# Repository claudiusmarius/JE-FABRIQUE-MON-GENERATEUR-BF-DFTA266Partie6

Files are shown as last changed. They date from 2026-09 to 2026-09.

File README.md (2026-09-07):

# JE-FABRIQUE-MON-GENERATEUR-BF-DFTA266Partie6

Générateur BF DDS -- AD9833 / Seeeduino XIAO / ATtiny85

Vidéo YouTube : https://youtu.be/ANECuOo78Ss

Présentation

Ce projet est la réalisation d'un générateur de fonctions basse
fréquence (BF) basé sur le circuit DDS AD9833, piloté par un
Seeeduino XIAO SAMD21 et associé à un ATtiny85.

L'appareil fournit trois formes d'onde :

Sinus

Triangle

Rectangle

La fréquence est sélectionnée par plages puis ajustée par appui sur deux boutons
poussoirs. Un afficheur OLED indique la fréquence et la forme d'onde
sélectionnée.

Le générateur dispose également de réglages de niveau, d'amplitude/gain
et d'offset, ainsi que d'un étage de sortie à transistors
complémentaires.

Architecture

Génération DDS

Le signal est produit par l'AD9833, commandé par le Seeeduino XIAO.

Le XIAO assure notamment : 
- la programmation de la fréquence ;
- la sélection de la forme d'onde ;
- la gestion des boutons ;
- la gestion de l'afficheur OLED.

Gestion des modes

Un ATtiny85 intervient dans la gestion des modes, notamment pour
l'atténuation automatique appliquée en mode rectangle afin de rapprocher
son niveau de celui des signaux sinus et triangle.

Traitement du signal

Le signal DDS est traité sur une carte analogique comprenant notamment
des NE5532 et un LT1006.

Cette partie assure : 
- l'adaptation du niveau ;
- le réglage del'amplitude ;
- le réglage de l'offset ;
- le traitement nécessaire avant l'étage de sortie.

Étage de sortie

L'étage de sortie utilise une paire complémentaire BD139 / BD140 en
push-pull.

La contre-réaction est prélevée à la jonction des deux résistances
d'émetteur, avant la résistance série de sortie. Elle participe à la
correction du fonctionnement de l'étage et à la réduction de la
distorsion de croisement.

Alimentation

L'appareil est alimenté en 24 V DC.

Une carte dédiée permet de créer une alimentation symétrique : - +12 V -
0 V - −12 V

Une même conception de PCB est utilisée, avec une implantation
différente, pour l'alimentation symétrique et pour l'étage push-pull.

Face avant

La face avant regroupe :

bouton d'augmentation de fréquence ;

bouton de diminution de fréquence ;

sélection de plage ;

sélection de forme d'onde ;

réglage du niveau du signal DDS ;

réglage du gain/amplitude ;

réglage d'offset ;

LED d'indication des modes ;

afficheur OLED ;

bornes de sortie.

Alimentation logique en 3,3 V

Au cours du développement, l'AD9833, l'ATtiny85 et l'afficheur OLED ont
été utilisés en 3,3 V, afin d'homogénéiser le domaine logique avec
le XIAO.

Cette évolution a également fait partie des essais visant à améliorer la
fiabilité du système lors des mises sous tension répétées.

Essais et mise au point

Le projet a été développé progressivement à partir d'essais sur
breadboard, de simulations, de mesures à l'oscilloscope et de
réalisations de PCB.

Des essais de fonctionnement prolongé et des cycles répétés de mise sous
tension ont également été réalisés.

Plusieurs corrections ont été apportées au cours du développement.

ERRATUMS

Les erreurs identifiées dans les schémas ou les PCB sont regroupées dans
la documentation sous la forme :

ERRATUM N°1, ERRATUM N°2, etc.

Chaque erratum précise : - l'erreur constatée ; - sa conséquence
éventuelle ; - la correction à appliquer ; - la révision de PCB
concernée.

Consulter impérativement les erratums avant toute reproduction d'une
carte.

Vidéos

Le projet est documenté sur YouTube sous la référence DFTA266 --
Générateur BF DDS.

Les liens vers les différentes vidéos peuvent être ajoutés dans cette
section.

Contenu du dépôt

Le dépôt peut notamment contenir :

schémas électroniques ;

fichiers PCB ;

fichiers Gerber ;

programmes du Seeeduino XIAO ;

programme de l'ATtiny85 ;

documentation technique ;

photographies ;

documents complémentaires ;

erratums et corrections.

Avertissement

Ce projet est une réalisation personnelle de laboratoire.

Les fichiers sont publiés pour documenter la conception et permettre à
d'autres passionnés d'étudier ou de reproduire le projet.

Avant toute reproduction, vérifier les schémas, les valeurs des
composants et les erratums correspondant à la révision du PCB
utilisée.

Contactez moi en cas de doute

Auteur

Claude DUFOURMONT

Projet personnel -- Générateur BF DDS

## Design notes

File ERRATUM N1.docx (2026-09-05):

ERRATUM N°1

Erreur constatée :

Sur certaines remises sous tension les ports du Seeeduino XIAO de niveau 3.3V étaient parfois perturbés vis les ports de 3 autres matériels alimentés en +5V.

PCB concerné :

DFTA266TER

Conséquences :

Ces perturbations pouvaient détruire dans certains cas le Seeeduino XIAO

Matériels impliqués :

AD9833

ATtiny85

Ecran OLED

Correction :

Le +5V continue d’alimenter le Seeeduino XIAO via la diode D3.

Le +3.3V du Seeeduino XIAO est utilisé pour se substituer aux pistes +5V des 3 matériels cités précédemment.

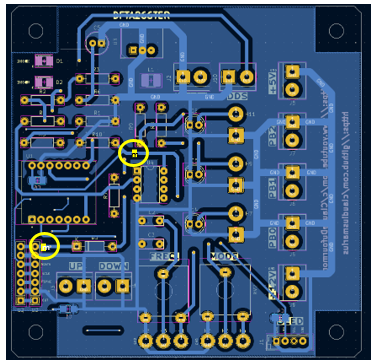
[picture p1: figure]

COUPURES DE PISTES SUR LA FACE B

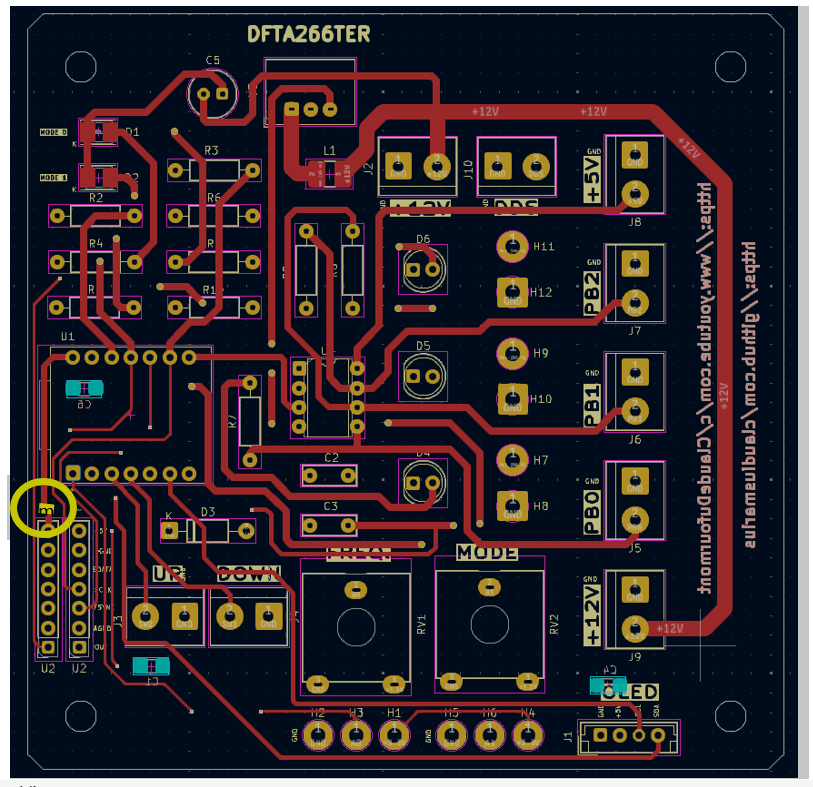
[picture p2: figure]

COUPURES DE PISTES SUR LA FACE F

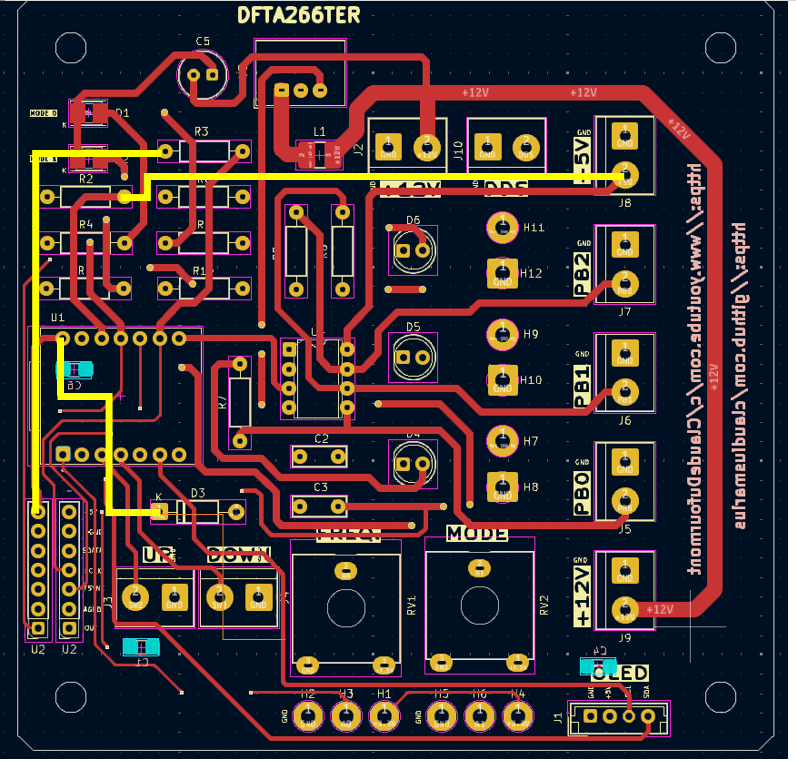
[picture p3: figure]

MISE EN PLACE DE NOUVELLES LIAISONS (sur la face de son choix)

Avant de procéder à la remis sous tension déposer le Seeeduino XIAO, l’AD9833, l’ATtiny85, l’écran OLED.

Mettre sous tension et

vérifier la présence de 5V sur le socket broche 14 du Seeeduino XIAO.

Vérifier l’absence de tension d’alimentation sur les connecteurs AD9833 ATtiny85 et OLED

Couper l’alimentation et mettre en place le Seeeduino XIAO, remettre sous tension.

Vérifier sur les connecteurs de AD9833, ATtiny85 et OLED la présence de 3.3V

Placer les 3 derniers composants et vérifier le bon fonctionnement.

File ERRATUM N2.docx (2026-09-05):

ERRATUM N°2

Erreur constatée :

Lorsque le PCB est utilisé pour la fonction DUAL SUPPLY, l’entrée moins de U1 aurait du être raccordée directement au GND c’est-à-dire au point d’intersection de R3 et R4

PCB concerné :

DFTA266Partie6

Conséquences :

Fonction inopérante

Matériels impliqués :

U1 ( AOP LT1006)

Correction :

Couper la liaison entre l’entrée moins de U1 (2) et sa sortie (6)

Couper la liaison entre l’entrée moins de U1 (2) et la résistance R11

Relier la sortie (6) à la résistance R11

Relier l’entrée moins de U1 à l’intersection de R3 et R4 qui est la masse virtuelle

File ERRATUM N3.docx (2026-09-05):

ERRATUM N°3

Erreur constatée :

Lorsque le PCB est utilisé pour la fonction DUAL SUPPLY, mais aussi pour la fonction PUSH PULL, une erreur d’inattention m’a fait inverser bas et collecteur de Q1, cette erreur est donc répercutée sur le PCB.

Pour la fonction PUSH PULL uniquement et pour des raisons de commodité relier la pin 1 de J3 au GND. ATTENTION : pas au point commun de R3 et R4 mais bien au GND c’est-à-dire à la pin 1 de J2.

PCB concerné :

DFTA266Partie6

Conséquences :

Fonction inopérante

Matériels impliqués :

Q1

Correction :

Couper les pistes de l’émetteur et du collecteur de Q1 et les croiser

Couper la liaison entre l’entrée moins de U1 (2) et la résistance R11

Relier la sortie (6) à la résistance R11

Relier l’entrée moins de U1 à l’intersection de R3 et R4 qui est la masse virtuelle

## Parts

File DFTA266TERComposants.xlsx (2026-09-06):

REF | Designation | Unité | Commentaires
C1 | 100 | nF | CMS
C2 | 100 | nF
C3 | 100 | nF
C4 | 100 | nF | CMS
C5 | 4.7 | µF | 50 à 100V
C6 | 100 | nF | CMS
D1 | LED CMS |  | Rouge LST672 | Gotronic 16910
D2 | LED CMS |  | Verte
D3
D4 | LED 5mm |  | Rouge | PB0 Sine
D5 | LED 5mm |  | Vert | PB1 Triangle
D6 | LED 5mm |  | Bleue | PB3 Square
J1
J2 |  |  | 2 Bornes | AliExpress
J3 |  |  | 3 pins | AliExpress
J4 |  |  | 3 pins | AliExpress
J5 |  |  | 3 pins | AliExpress
J6 |  |  | 3 pins | AliExpress
J7 |  |  | 3 pins | AliExpress
J8 |  |  | 3 Bornes | AliExpress
J9
J10
L1 |  | µH | Recom | RS Particulier 1855864
R1 |  | K | NON INSTALLEE | Gotronic 04099
R2 |  | K | NON INSTALLEE | Gotronic 04099
R3 |  | K | NON INSTALLEE | Gotronic 04099
R4 | 820 | Ω |  | Gotronic 04099
R5 | 820 | Ω |  | Gotronic 04099
R6 |  | K | NON INSTALLEE | Gotronic 04099
R7 | 330 | Ω |  | Gotronic 04099
R8 | 100 | Ω |  | Gotronic 04099
R9 | 330 | Ω |  | Gotronic 04099
R10 |  | K | NON INSTALLEE | Gotronic 04099
RV1 | 10 | K |  | Gotronic 04099
RV2 | 10 | K
U1 | Seeeduino XIAO |  | + 2 pin sockets 7 pins | Rs Particulier 6612066
U2 | AD9833 |  |  | AliExpress
U3 | R-78E5.0-0.2
U4 | ATtiny85 20U |  | + Socket 8 pins

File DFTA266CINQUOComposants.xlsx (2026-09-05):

REF | Designation | Unité | Commentaires
C1 | 22 | µF
C2 | 100 | nF
C3 | 100 | nF | CMS
C4 | 100 | nF | CMS
C5 | 10 | pF
C6 | 10 | pF | NE PAS INSTALLER
J1 |  |  | 2 Bornes
J2 |  |  | 2 Bornes | AliExpress
J3 |  |  | 2 Bornes | AliExpress
J4 |  |  | 3 Bornes | AliExpress
J5 |  |  | 3 Bornes
Q1 | 2N2222
R1 | 4.7 | K |  | Gotronic 04099
R2 | 4.7 | K |  | Gotronic 04099
R3 | 4.7 | K |  | Gotronic 04099
R4 | 4.7 | K |  | Gotronic 04099
R5 | 100 | Ω |  | Gotronic 04099
R6 | 15 | K |  | Gotronic 04099
R7 | 1 | K |  | Gotronic 04099
R8 | 680 | Ω |  | Gotronic 04099
R9 | 1 | K |  | Gotronic 04099
R10 | 1 | K |  | Gotronic 04099
R11 | 2.2 | K |  | Gotronic 04099
R12 | 2.2 | K |  | Gotronic 04099
R13 | 2.2 | K |  | Gotronic 04099
R14 | 2.2 | K |  | Gotronic 04099
R15 | 270 | Ω |  | Gotronic 04099
R16 | 270 | Ω | IL FAUT LA STRAPPER | Gotronic 04099
R17 | 100 | Ω |  | Gotronic 04099
R18 | 100 | Ω |  | Gotronic 04099
R19 | 180 | K |  | Gotronic 04099
RV1 | 500 | Ω
RV2 | 10 | K
RV3 | 10 | K
RV4 | 10 | K
RV5 | 10 | K
U1 | NE5532 |  | + Socket 8 pins
U2 | NE5532 |  | + Socket 8 pins
U3 | LT1106 |  | + Socket 8 pins

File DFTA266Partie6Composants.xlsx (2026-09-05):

 | PUSH PULL |  | DUAL SUPPLY
REF | Designation | Unité | Designation | Unité
C1 | ABSENT |  | 100 | nF
C2 | ABSENT |  | 100 | nF
C3 |  |  | 220µF 50V
C4 |  |  | 220µF 50V
D1 | 1N4148 |  | 0 | Ω
D2 | 1N4148 |  | 0 | Ω
HS1
HS2
J1 |  |  | ABSENT
J2
J3 | ABSENT
J4 |  |  | ABSENT
Q1 | BD140
Q2 | BD139
R1 | ABSENT |  | 100 | KΩ
R2 | ABSENT |  | 100 | KΩ
R3 | 2.2 | Ω | 0.5 | Ω | 1 | je n'avais pas de 0,5 Ω j'ai remplacé des 1 Ω, pas de problème
R4 | 2.2 | Ω | 0.5 | Ω | 1
R5 | ZERO (strapp) |  | 47 | Ω
R6 | ZERO (strapp) |  | 47 | Ω
R7 | 2.2 | KΩ | ABSENT
R8 | 2.2 | KΩ | ABSENT
R9 | ABSENT |  | 0 | Ω
R10 | ZERO (strapp) |  | ABSENT
R11 | ABSENT |  | 0 | Ω
R12 | 100 | Ω | ABSENT
RV1 | ABSENT |  | 10 | KΩ
U1 | ABSENT |  | LT1006 et sa socket 8 pins

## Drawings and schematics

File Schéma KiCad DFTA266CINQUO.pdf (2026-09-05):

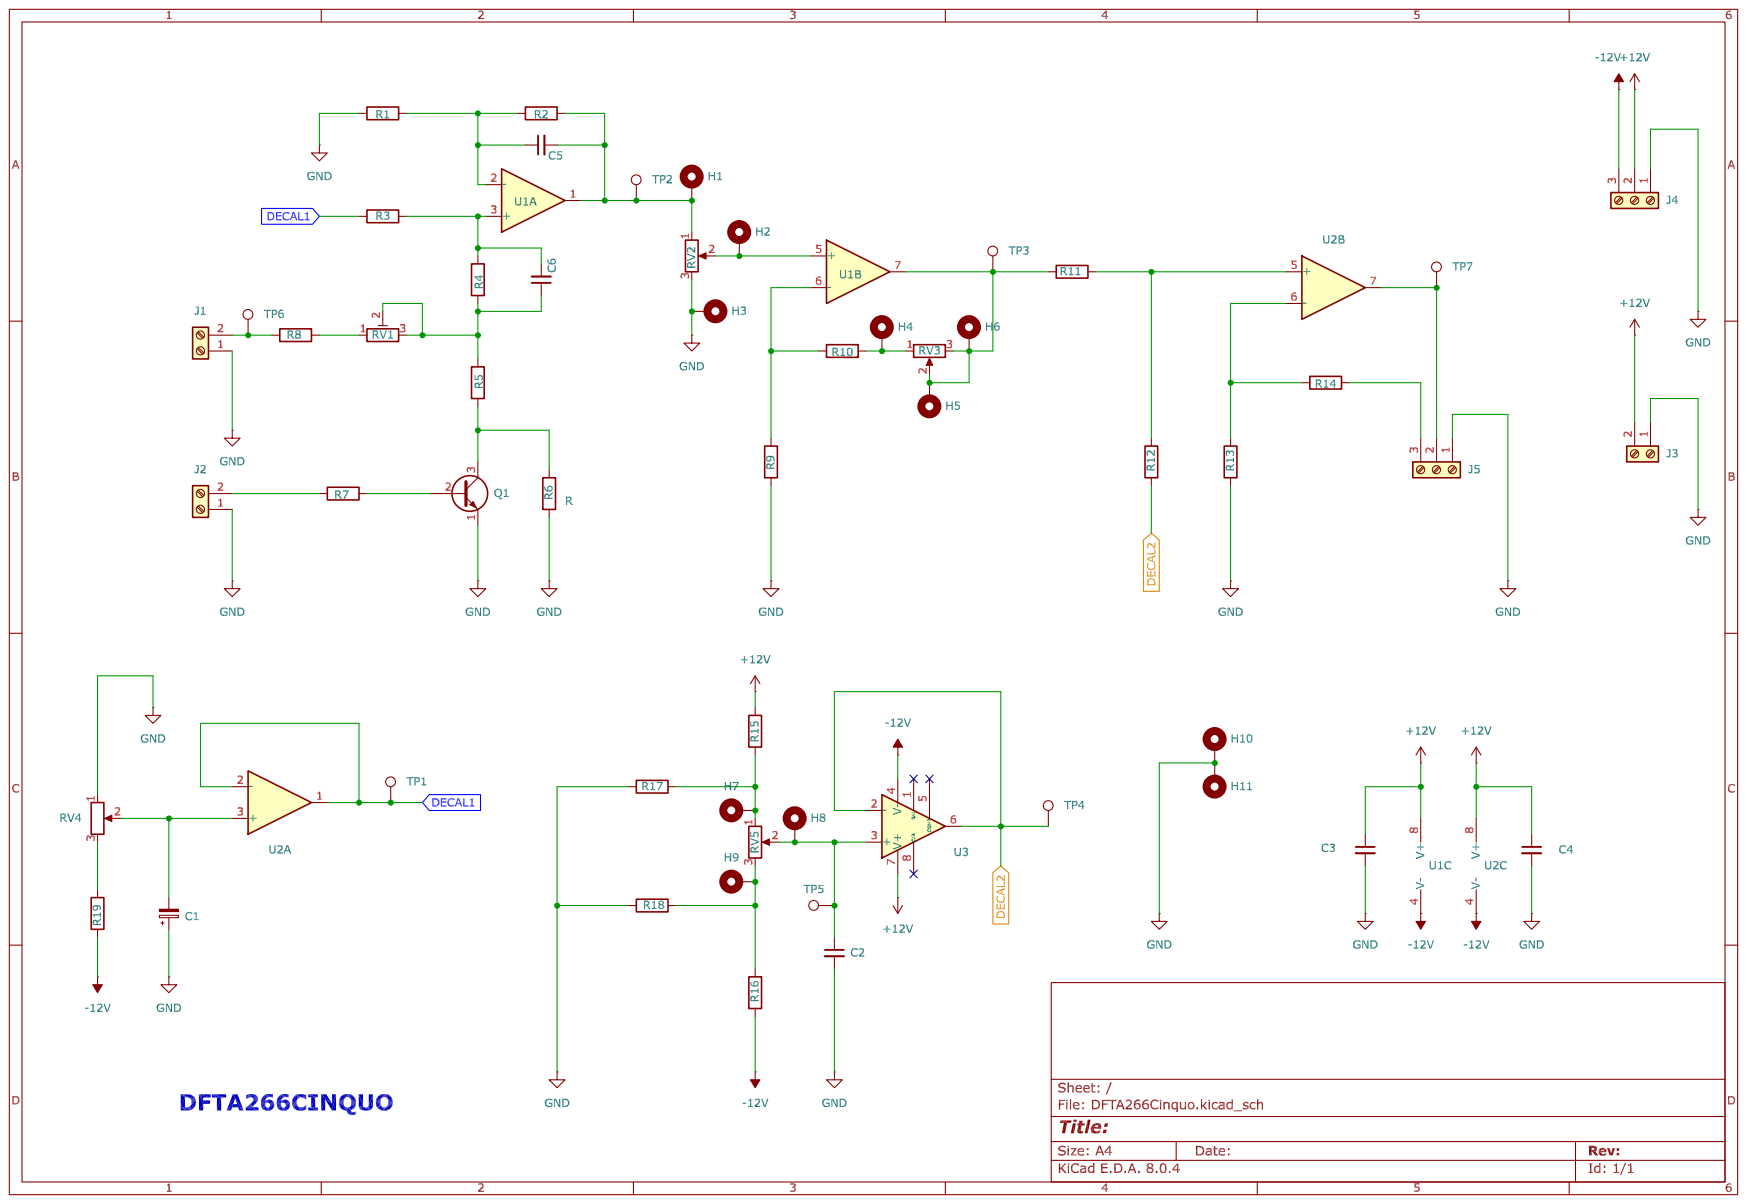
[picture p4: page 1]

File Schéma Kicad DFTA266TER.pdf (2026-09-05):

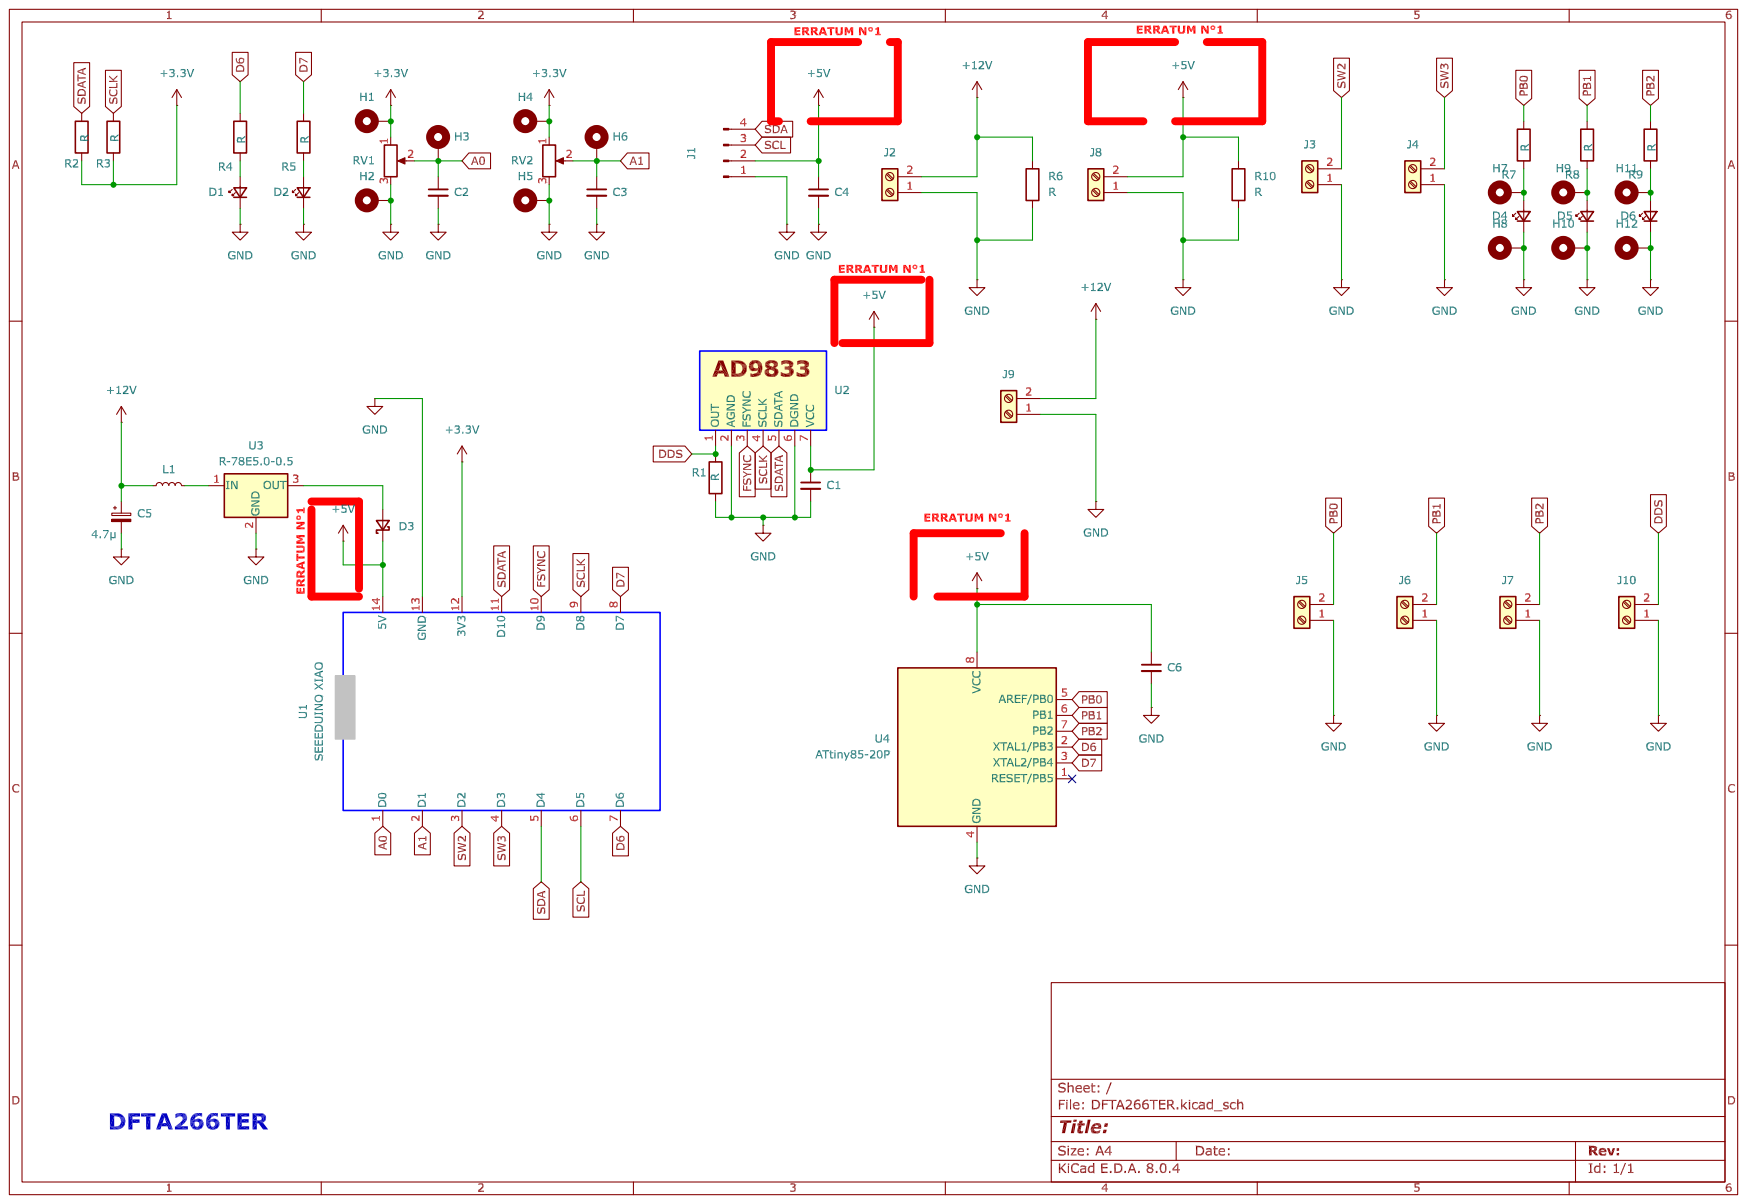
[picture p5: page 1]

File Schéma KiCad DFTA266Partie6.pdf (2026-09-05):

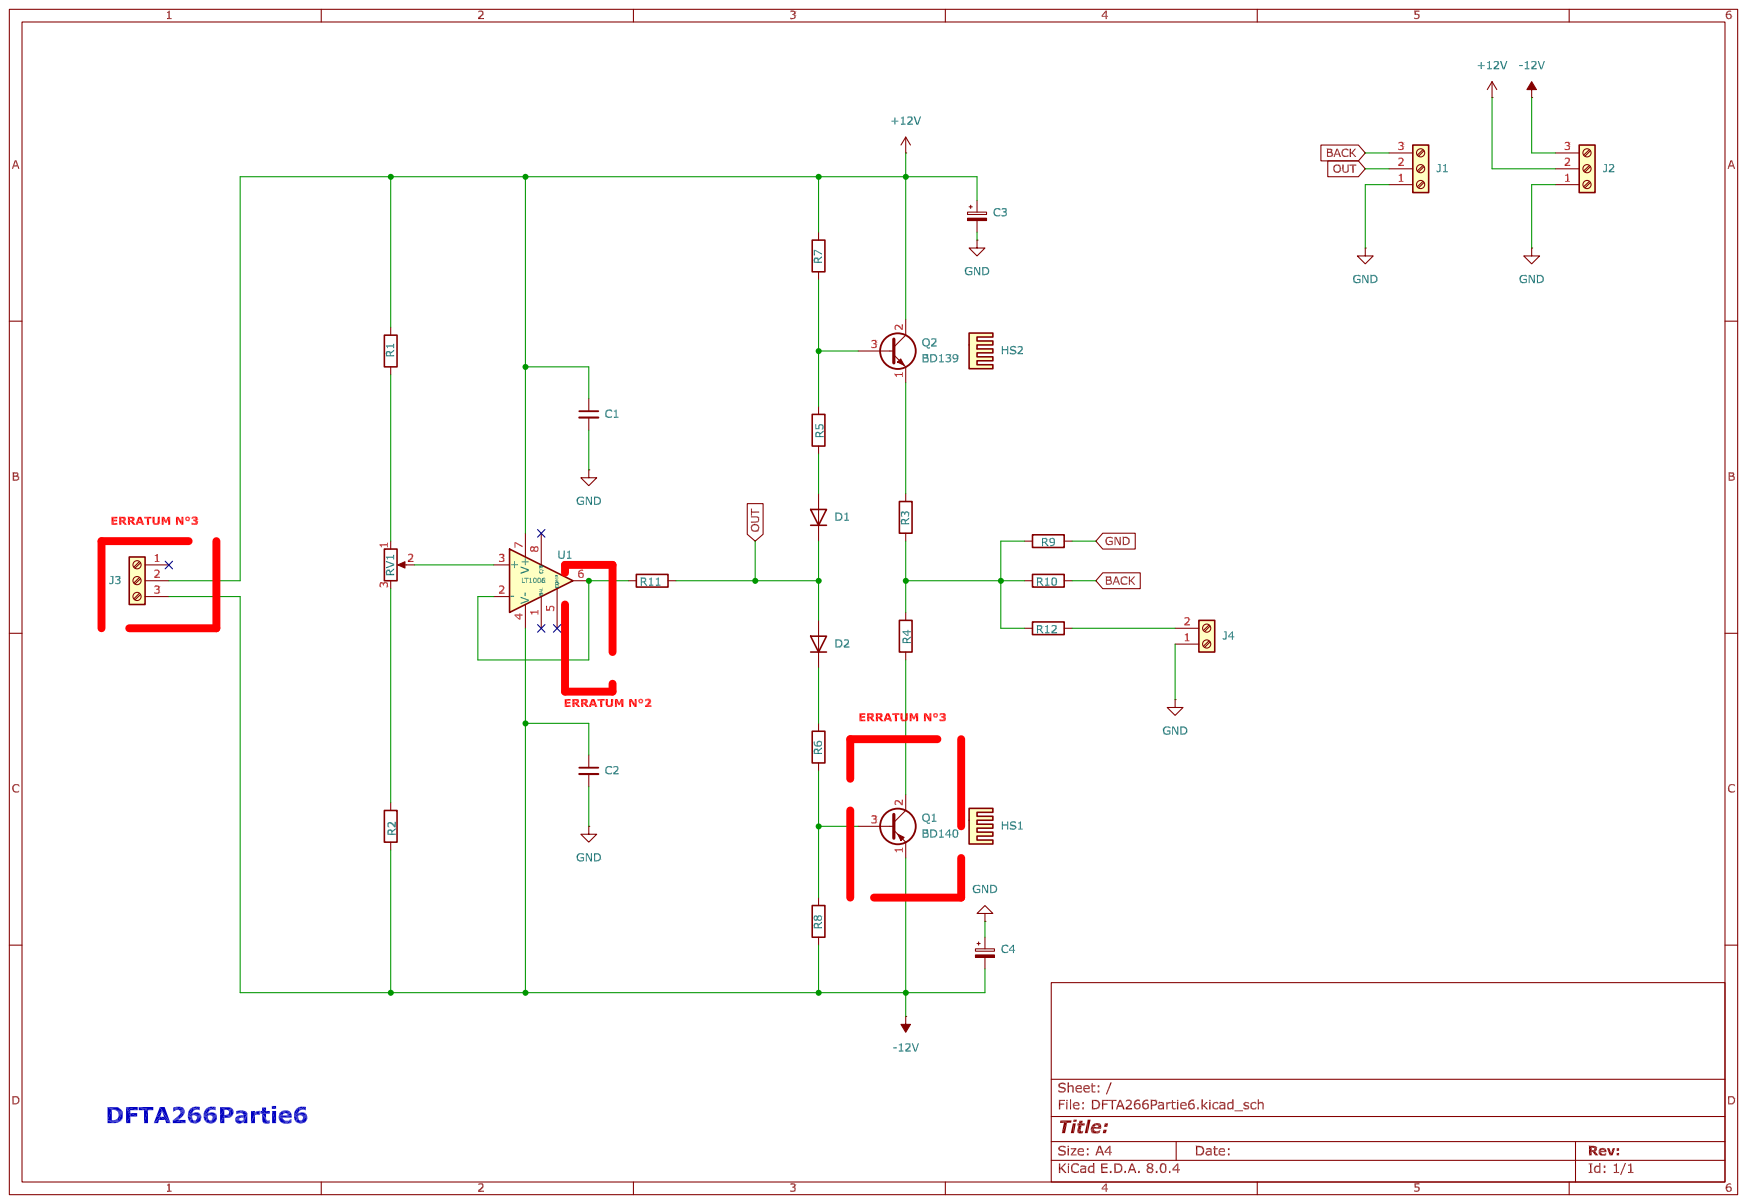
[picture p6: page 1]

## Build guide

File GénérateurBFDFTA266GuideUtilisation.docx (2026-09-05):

claudiusmarius

GUIDE GENERATEUR BF

https://www.youtube.com/c/ClaudeDufourmont

https://github.com/claudiusmarius

Claude DUFOURMONT

04/09/2026

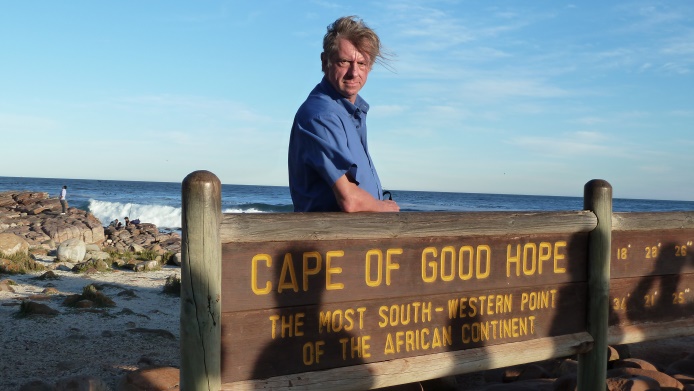
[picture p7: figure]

Indice | Date | Observations
0 | 04/09/2026 | Création du document

## Guide technique, réalisation, réglages et mise en service

# 1. Introduction

Ce document décrit la conception, la réalisation, les réglages et la mise en service d'un générateur BF basé sur un circuit DDS AD9833.

L'objectif de ce projet est de réaliser progressivement un générateur de fonctions complet, en séparant les différentes fonctions électroniques sur plusieurs cartes.

Cette méthode permet de tester et de valider chaque sous-ensemble indépendamment avant son intégration dans l'appareil final.

Le générateur est organisé autour de plusieurs fonctions principales :

- génération numérique du signal ;
- sélection de la fréquence ;
- sélection de la forme d'onde ;
- affichage des paramètres ;
- traitement analogique du signal ;
- réglage de l'amplitude ;
- création des tensions de décalage ;
- amplification de puissance ;
- alimentation des différents étages.

Le projet est volontairement réalisé sous forme de blocs fonctionnels indépendants.

Cette architecture permet également de modifier ou de remplacer ultérieurement un étage sans remettre en cause l'ensemble du générateur.

### Documentation associée

Le projet complet est disponible dans le dépôt GitHub :

[LIEN À AJOUTER — dépôt GitHub principal du générateur BF]

Les différentes étapes de réalisation sont également présentées dans les vidéos de la chaîne YouTube

# 2. Présentation générale du générateur

Le générateur est constitué de plusieurs cartes électroniques.

L'architecture générale est la suivante :

Interface (face avant) :

Une plaquette pour générer le signal DDS

Potentiomètre Gamme

Potentiomètre forme d’onde

Bouton UP et DOWN pour la fréquence

Ecran OLED

Potentiomètre d’amplitude

Potentiomètre de gain

Potentiomètre de décalage d’offset

Douilles bananes pour la sortie du signal

Voyant présence tension

PCB DFTA266TER

C’est lui qui fournit le signal DDS grâce à l’AD9833 et le Seeeduino XIAO.

Il est équipé également d’ ATtiny85 pour permettre d’afficher le mode sélectionné

PCB DFTA266CINQUO :

Il est placé en « sandwich » juste au-dessus de la carte DDS.

C’est la plaquette de traitement du signal, elle apporte les décalages de mise en forme du signal et permet de gérer l’amplitude du signal et son offset vis-à-vis du zéro volt.

PCB DFTAPartie6 dans sa configuration PUSH PULL:

Dans sa configuration PUSH PULL il amplifie en courant le signal fourni par la carte de traitement du signal et intervient en contre réaction avec l’AOP de sortie de cette dernière

PCB DFTAPartie6 dans sa configuration DUAL SUPPLY

Il est alimenté à partir de mon alimentation polyvalente SMART TINY POWER SUPPLY (voir vidéo DFTA179)

Ici j’ai fait le choix d’une source 24 V, à partir de laquelle sont obtenues les différentes tensions + et -12V aux circuits numériques et analogiques.

# 3. Générateur DDS et réglages

## 3.1 Principe du DDS

Le générateur de fonctions utilise un circuit AD9833, qui constitue le cœur de la génération du signal.

Le DDS permet de programmer numériquement la fréquence et de sélectionner différentes formes d'onde.

L'AD9833 dispose notamment d'un accumulateur de phase de 28 bits et peut générer des signaux sinus, triangle ou carré. Sa fréquence de sortie est programmable par une interface série à trois fils.

## 3.2 AD9833

Dans ce projet, l'AD9833 est utilisé comme générateur de signal programmable.

La programmation est réalisée par le Seeeduino XIAO.

Les trois lignes de communication utilisées sont :

- SCLK ;
- SDATA ;
- FSYNC.

L'AD9833 est alimenté sous 3.3 V dans cette réalisation.

Le signal généré par le DDS est ensuite transmis à l'étage de traitement analogique.

## 3.3 Seeeduino XIAO

Le Seeeduino XIAO assure la gestion principale de la carte DDS.

Il réalise notamment :

- la programmation de l'AD9833 ;
- la lecture des potentiomètres ;
- la gestion des boutons UP et DOWN ;
- la gestion de l'affichage OLED ;
- la sélection de la fréquence ;
- la sélection de la forme d'onde.
- La fourniture de la tension de 3.3V

Le code correspondant est disponible dans le dépôt GitHub du projet.

## 3.4 ATtiny85

Un ATtiny85 est également présent sur la carte.

Il est utilisé pour assurer certaines fonctions de décodage (pilotage des LEDs SIN TRI et SQR ) et de commande qui seront également exploitées par les étages analogiques.

Cette séparation permet de conserver une architecture simple entre la gestion numérique du générateur et les fonctions particulières nécessaires au traitement du signal.

Le code correspondant est disponible dans le dépôt GitHub du projet.

## 3.5 Sélection des gammes de fréquence

Le premier potentiomètre permet de sélectionner la gamme de fréquence.

Les gammes retenues sont :

- 1 Hz ;
- 10 Hz ;
- 100 Hz ;
- 1 kHz ;
- 10 kHz ;
- 100 kHz.

Le potentiomètre ne règle donc pas directement la fréquence finale : il détermine principalement le domaine dans lequel les boutons UP et DOWN vont agir.

## 3.6 Réglage fin de la fréquence

Deux boutons-poussoirs permettent ensuite de modifier précisément la fréquence :

- UP : augmentation de la fréquence ;
- DOWN : diminution de la fréquence.

La fréquence résultante est affichée en temps réel sur l'écran OLED.

## 3.7 Sélection de la forme d'onde

Le deuxième potentiomètre permet de sélectionner la forme d'onde.

Les trois modes disponibles sont :

- SINE ;
- TRIANGLE ;
- SQUARE.

L'AD9833 permet directement cette sélection par sa programmation interne.

## 3.8 Affichage OLED

Un écran OLED à interface I²C permet d'afficher en temps réel :

- la fréquence programmée ;
- la forme d'onde sélectionnée.

L'écran peut éventuellement être remplacé par un modèle de dimensions différentes moyennant les adaptations nécessaires du programme.

## 3.9 Programmation et mise en service

Avant la première mise sous tension, programmer :

1. le Seeeduino XIAO ;
2. l'ATtiny85.

Pour la programmation de l'ATtiny85, le programmateur décrit dans la vidéo DFTA235 peut être utilisé :

DFTA235 Le MEILLEUR programmateur DIY pour ATtiny84 & 85 (schémas + GitHub inclus)

https://youtu.be/-_KMgezaRH0

# 4. Traitement du signal

Le signal fourni directement par l'AD9833 constitue le point de départ du traitement analogique.

Les différents modes ne présentent pas nécessairement le même niveau de sortie.

Dans la réalisation actuelle, le signal sinus et le signal triangle présentent une amplitude sensiblement inférieure à celle du signal carré.

Cette différence doit donc être prise en compte dans les étages analogiques suivants.

## 4.1 Amplification

Le premier objectif du traitement analogique est d'adapter le niveau fourni par le DDS aux besoins de l'étage de sortie.

Les gains sont déterminés par les rapports de résistances des amplificateurs opérationnels.

Les valeurs retenues sont indiquées dans les listes de composants

## 4.2 Décalages continus

Certains étages nécessitent l'introduction d'une tension continue de décalage.

Ces tensions sont générées à partir de potentiomètres et tamponnées par des amplificateurs opérationnels utilisés en suiveurs.

Une attention particulière doit être portée à la polarité de ces tensions.

## 4.3 Soustracteurs

Les amplificateurs opérationnels utilisés dans cette partie permettent notamment de réaliser les fonctions de soustraction nécessaires au recentrage du signal.

Le principe est d'ajouter ou de soustraire une tension continue au signal alternatif afin d'obtenir la position souhaitée par rapport au zéro volt.

## 4.4 Réglage de l'amplitude

Un réglage d'amplitude est prévu afin d'adapter le niveau du signal disponible en sortie du traitement analogique.

Le réglage doit être effectué en tenant compte :

- de la forme d'onde ;
- de la fréquence ;
- de la tension d'alimentation ;
- des limites d'excursion des amplificateurs opérationnels ;
- de la charge connectée en sortie.

## 4.5 Cas particulier du signal carré

Le signal carré fourni par l'AD9833 présente un niveau différent de ceux des signaux sinus et triangle.

Dans cette réalisation, son amplitude est donc automatiquement réduite avant l'étage de sortie.

Cette fonction est commandée par le port PB2 de l'ATtiny85.

Le signal de commande actionne un transistor bipolaire qui connecte une résistance supplémentaire au circuit d'amplitude.

Le choix d'un transistor bipolaire plutôt que d'un MOSFET a été conservé après essais pratiques sur breadboard.

Cette décision est un exemple de choix effectué à partir du comportement réel du montage et non uniquement de considérations théoriques.

# 5. Étage de sortie push-pull

L'étage de sortie constitue le dernier étage analogique avant la borne de sortie du générateur.

Son rôle est notamment d'assurer une capacité de courant supérieure à celle disponible directement en sortie des amplificateurs opérationnels utilisés dans les étages précédents.

## 5.1 Principe

L'étage utilise une paire complémentaire de transistors :

- BD139 ;
- BD140.

Ces transistors sont montés en configuration push-pull.

Cette configuration permet aux deux transistors de prendre en charge alternativement les alternances du signal.

Ces transistors sont montés sur dissipateurs individuels attention ils sont montés sans isolants, les dissipateurs ne doivent pas se toucher et ne doivent pas toucher la carcasse métallique.

## 5.2 Réglage

Le réglage de l'étage de sortie doit être effectué avec soin afin de rechercher un compromis entre :

- distorsion de croisement ;
- courant de repos ;
- échauffement ;
- amplitude disponible.

# 6. Alimentation 24 V

L'alimentation générale du générateur est basée sur une tension continue de 24 V.

Cette tension constitue la source commune permettant de distribuer l'énergie aux différentes cartes.

Le choix du 24 V permet notamment de disposer d'une réserve de tension suffisante pour les étages analogiques.

Une partie de cette tension est convertie en 5 V pour les circuits nécessitant cette alimentation.

# 7. Alimentation symétrique à zéro virtuel

L'étage analogique nécessite une alimentation symétrique afin de pouvoir traiter des signaux centrés autour de 0 V.

La solution retenue consiste à partir de l'alimentation 24 V et à créer deux tensions symétriques :

+12 V / 0 V / −12 V

Le zéro utilisé par les étages analogiques est un zéro virtuel.

## 7.1 Principe

Le 24 V est partagé afin d'obtenir une référence située approximativement au milieu de l'alimentation.

Cette référence est ensuite tamponnée afin de pouvoir fournir le courant nécessaire aux différents étages.

Le zéro virtuel ne doit donc pas être considéré comme une simple jonction résistive : sa stabilité et son impédance sont essentielles au bon fonctionnement du circuit analogique.

## 7.2 Particularité de conception : carte commune

Un point important de cette réalisation concerne les PCB utilisés pour :

- l'alimentation à zéro virtuel ;
- l'étage de sortie push-pull.

Basiquement, il s'agit du même PCB.

Le circuit imprimé a été conçu pour être suffisamment polyvalent afin de recevoir des composants et des réglages différents selon la fonction recherchée.

Cette méthode permet de limiter le nombre de PCB différents à concevoir et à fabriquer, tout en conservant des fonctions électroniques distinctes.

# 8. Architecture mécanique et organisation des cartes

Cette partie sera complétée lorsque l'ensemble des cartes sera définitivement installé dans le boîtier.

Elle décrira notamment :

- l'emplacement de chaque PCB ;
- L’alimentation 24V DC est montée sur la face arrière ;
- L’alimentation symétrique est montée sur la face inférieure, à gauche ;
- Le générateur DDS est monté au centre toujours sur la face inférieure
- Le Push PULL est monté à droite ;

# 9. Mise en service et procédure de contrôle

La mise en service doit être réalisée progressivement.

Il est recommandé de vérifier séparément chaque tension d'alimentation avant de connecter les différents étages.

### Ordre recommandé

1. Vérifier l'absence de court-circuit hors tension.
2. Vérifier l'alimentation 24 V.
3. Vérifier les tensions +12 V et −12 V.
4. Vérifier le 5 V.
5. Mettre en service la carte DDS.
6. Vérifier la sortie directe de l'AD9833.
7. Vérifier les trois formes d'onde.
8. Vérifier les différentes gammes de fréquence.
9. Vérifier l'affichage OLED.
10. Vérifier les boutons UP et DOWN.
11. Connecter le traitement analogique.
12. Vérifier les amplitudes et les décalages.
13. Mettre en service l'étage push-pull.
14. Vérifier la sortie finale.

# 10. Erratums et corrections des PCB

Cette section est volontairement séparée du reste de la documentation.

Certaines erreurs ont été découvertes après fabrication des PCB.

Elles ne remettent pas nécessairement en cause la réalisation des cartes, mais doivent être clairement documentées afin que toute personne réalisant le projet puisse effectuer les corrections nécessaires.

- Voir les 3 documents ERRATUM traitant leur solutionnement

[Les corrections devront être réalisées avant la première mise sous tension lorsque l'erreur concerne une alimentation ou une connexion susceptible d'endommager un composant.

# 11. Essais et résultats

Ultérieurement

# 12. Dépannage

Cette section regroupera les problèmes rencontrés pendant la mise au point.

Elle sera particulièrement utile pour distinguer une erreur de câblage d'un défaut de composant.

Exemples de symptômes à documenter :

### Pas d'affichage OLED

Vérifier :

- alimentation 3.3V ;
- masse ;
- lignes I²C ;
- programmation du XIAO ;
- adresse I²C.

### Pas de signal DDS

Vérifier :

- alimentation de l'AD9833 ;
- connexion SCLK ;
- SDATA ;
- FSYNC ;
- programmation du XIAO ;
- présence du signal à la sortie DDS.

### Signal correct sur DDS mais incorrect après traitement

Vérifier :

- alimentations ±12 V ;
- AOP ;
- résistances ;
- tensions de décalage ;
- réglage d'amplitude ;
- commande du mode carré.

### Signal correct avant le push-pull mais incorrect en sortie

Vérifier :

- BD139 ;
- BD140 ;
- courant de repos ;
- polarisation ;
- résistances d'émetteur ; charge de sortie.

# 13. Conclusion

Ce générateur BF a été conçu selon une approche modulaire.

Chaque fonction importante est isolée sur une carte ou un sous-ensemble identifiable afin de faciliter :

- la mise au point ;
- les mesures ;
- la maintenance ;
- les modifications futures ;
- et la reproduction du projet.

La documentation complète, les schémas, les fichiers PCB et les programmes sont regroupés dans le dépôt GitHub du projet.

Les vidéos YouTube associées au projet permettent de compléter cette documentation en montrant les étapes de réalisation, les essais et le fonctionnement réel de l'appareil.

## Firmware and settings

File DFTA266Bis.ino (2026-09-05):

#include <SPI.h>
#include <Wire.h>
#include <MD_AD9833.h>
#include <Adafruit_GFX.h>
#include <Adafruit_SSD1306.h>

// --------------------
// AD9833
// --------------------
#define SDATA 10
#define SCLK  8
#define FSYNC 9
MD_AD9833 AD(SDATA, SCLK, FSYNC);

// --------------------
// OLED 128x32
// --------------------
#define SCREEN_WIDTH 128
#define SCREEN_HEIGHT 32
#define OLED_ADDR 0x3C
#define OLED_RESET -1
Adafruit_SSD1306 display(SCREEN_WIDTH, SCREEN_HEIGHT, &Wire, OLED_RESET);

// --------------------
// Entrées
// --------------------
#define POT_PIN   A0
#define MODE_POT  A1
#define BTN_UP    2
#define BTN_DOWN  3

// LEDs
#define LED_MODE0 6
#define LED_MODE1 7

// --------------------
// Plages
const long minF[6] = {1, 10, 100, 1000, 10000, 100000};
const long maxF[6] = {10, 100, 1000, 10000, 100000, 1000000};

// --------------------
int currentRange = -1;
long currentFreq = 0;
long offset = 0;

// pot fréquence
float filteredPot = 0;
const float alpha = 0.02;

// 🔥 SUPPRESSION filtre mode
int lastMode = -1;

// Sample & Hold
long lastPotRange = -1;
unsigned long lastPotChangeTime = 0;
const int POT_STABLE_TIME = 200;

// boutons
unsigned long lastPress = 0;
const unsigned long DEBOUNCE_MS = 30;
bool lastUpState = HIGH;
bool lastDownState = HIGH;

// noms des modes pour OLED
const char* modeNames[] = {"SINE", "TRIANGLE", "SQUARE"};

// --------------------
void setup() {
  delay(200);

  Wire.begin();
  Wire.end();
  delay(10);
  Wire.begin();
  delay(10);

  analogReadResolution(12);

  pinMode(BTN_UP, INPUT_PULLUP);
  pinMode(BTN_DOWN, INPUT_PULLUP);
  pinMode(LED_MODE0, OUTPUT);
  pinMode(LED_MODE1, OUTPUT);

  if (!display.begin(SSD1306_SWITCHCAPVCC, OLED_ADDR)) while(1);
  delay(50);

  display.clearDisplay();
  display.display();
  delay(50);

  AD.begin();
  AD.setMode(MD_AD9833::MODE_SINE);

  // 🔥 INITIALISATION
  filteredPot = analogRead(POT_PIN);
  int initRange = filteredPot / 683;
  if (initRange > 5) initRange = 5;
  if (initRange < 0) initRange = 0;

  currentRange = initRange;
  lastPotRange = initRange;

  offset = 0;
  currentFreq = minF[currentRange];
  AD.setFrequency(MD_AD9833::CHAN_0, currentFreq);

  // init mode
  int modeADC = analogRead(MODE_POT);
  if (modeADC < 1365) lastMode = 0;
  else if (modeADC < 2730) lastMode = 1;
  else lastMode = 2;

  switch (lastMode) {
    case 0: AD.setMode(MD_AD9833::MODE_SINE); break;
    case 1: AD.setMode(MD_AD9833::MODE_TRIANGLE); break;
    case 2: AD.setMode(MD_AD9833::MODE_SQUARE1); break;
  }

  displayFreq(currentFreq);
}

// --------------------
void loop() {
  if (currentRange < 0) return;

  // --- lecture pot fréquence ---
  int potADC = analogRead(POT_PIN);
  filteredPot = alpha * potADC + (1 - alpha) * filteredPot;

  int newRange = filteredPot / 683;
  if (newRange > 5) newRange = 5;

  if (newRange != lastPotRange) {
    lastPotChangeTime = millis();
    lastPotRange = newRange;
  }

  if (millis() - lastPotChangeTime > POT_STABLE_TIME) {
    if (newRange != currentRange) {
      currentRange = newRange;
      offset = 0;
    }
  }

  // --- mode ---
  int modeADC = analogRead(MODE_POT);
  int newMode = 0;
  if (modeADC < 1365) newMode = 0;
  else if (modeADC < 2730) newMode = 1;
  else newMode = 2;

  if (newMode != lastMode) {
    lastMode = newMode;

    switch (newMode) {
      case 0: AD.setMode(MD_AD9833::MODE_SINE); break;
      case 1: AD.setMode(MD_AD9833::MODE_TRIANGLE); break;
      case 2: AD.setMode(MD_AD9833::MODE_SQUARE1); break;
    }

    displayFreq(currentFreq);
  }

  // --- LEDs ---
  switch (lastMode) {
    case 0: digitalWrite(LED_MODE0, LOW); digitalWrite(LED_MODE1, LOW); break;
    case 1: digitalWrite(LED_MODE0, HIGH); digitalWrite(LED_MODE1, LOW); break;
    case 2: digitalWrite(LED_MODE0, LOW); digitalWrite(LED_MODE1, HIGH); break;
  }

  // --- boutons ---
  handleButtons();

  // --- calcul fréquence ---
  long rawFreq = minF[currentRange] + offset;
  long step = getStep(currentRange);

  long newFreq;
  if (currentRange == 0) newFreq = minF[0] + offset; // 1–10 Hz précis
  else newFreq = minF[currentRange] + ((offset / step) * step);

  if (newFreq < minF[currentRange]) newFreq = minF[currentRange];
  if (newFreq > maxF[currentRange]) newFreq = maxF[currentRange];

  long threshold = (currentRange == 0) ? 0 : 5;
  if (abs(newFreq - currentFreq) > threshold) {
    currentFreq = newFreq;
    AD.setFrequency(MD_AD9833::CHAN_0, currentFreq);
    displayFreq(currentFreq);
  }
}

// --------------------
long getStep(int range) {
  switch (range) {
    case 0: return 1;
    case 1: return 2;   // 10–100 Hz step initial
    case 2: return 5;   // 100–1000 Hz step initial
    case 3: return 5;
    case 4: return 20;
    case 5: return 100;
    default: return 1;
  }
}

// --------------------
bool readButton(int pin, bool &lastState) {
  bool state = digitalRead(pin);
  if (state != lastState) {
    delay(DEBOUNCE_MS);
    state = digitalRead(pin);
  }
  lastState = state;
  return state == LOW;
}

// --------------------
void handleButtons() {
  static unsigned long pressStart = 0;
  static bool btnHeld = false;

  bool up = readButton(BTN_UP, lastUpState);
  bool down = readButton(BTN_DOWN, lastDownState);
  unsigned long now = millis();

  if (up || down) {
    if (!btnHeld) {
      pressStart = now;
      btnHeld = true;
    }

    unsigned long heldTime = now - pressStart;
    long step;
    unsigned long tempo;

    // --- logique par plage ---
    switch (currentRange) {
      case 0: // 1–10Hz
        step = 1;
        tempo = 150;
        break;
      case 1: // 10–100Hz
        step = 2 + heldTime / 300; // step progressif
        if (step > 10) step = 10;
        tempo = 80;
        break;
      case 2: // 100–1000Hz
        step = 5 + heldTime / 200; // step progressif
        if (step > 50) step = 50;
        tempo = 70;
        break;
      default: // >1 kHz
        step = getStep(currentRange) * (1 + heldTime / 200);
        long maxStep = (maxF[currentRange] - minF[currentRange]) / 10;
        if (step > maxStep) step = maxStep;
        tempo = 50;
        break;
    }

    if (now - lastPress > tempo) {
      if (up) offset += step;
      if (down) offset -= step;

      if (offset < 0) offset = 0;
      long maxOffset = maxF[currentRange] - minF[currentRange];
      if (offset > maxOffset) offset = maxOffset;

      lastPress = now;
    }
  } else {
    btnHeld = false;
  }
}

// --------------------
void displayFreq(long freq) {
  display.clearDisplay();
  display.setTextColor(SSD1306_WHITE);

  char buffer[16];
  if (freq < 1000) sprintf(buffer, "%ld Hz", freq);
  else if (freq < 10000) sprintf(buffer, "%.2f kHz", freq / 1000.0);
  else if (freq < 100000) sprintf(buffer, "%.1f kHz", freq / 1000.0);
  else sprintf(buffer, "%ld kHz", freq / 1000);

  display.setTextSize(1);

  int16_t x1, y1;
  uint16_t w, h;
  display.getTextBounds(buffer, 0, 0, &x1, &y1, &w, &h);
  int cursorX = (SCREEN_WIDTH - w) / 2;
  int cursorY = (SCREEN_HEIGHT - h) / 2 - 4;
  display.setCursor(cursorX, cursorY);
  display.print(buffer);

  const char* modeStr = modeNames[lastMode];
  display.getTextBounds(modeStr, 0, 0, &x1, &y1, &w, &h);
  cursorX = (SCREEN_WIDTH - w) / 2;
  cursorY += h + 2;
  display.setCursor(cursorX, cursorY);
  display.print(modeStr);

  display.display();
}

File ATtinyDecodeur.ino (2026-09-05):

#define IN_A 3
#define IN_B 4

#define LED_SINE     0
#define LED_TRIANGLE 1
#define LED_SQUARE   2

int lastMode = -1;

int getMode() {
  int A = digitalRead(IN_A);
  int B = digitalRead(IN_B);

  if (A == 0 && B == 0) return 0; // SINE
  if (A == 1 && B == 0) return 1; // TRIANGLE
  return 2;                       // SQUARE
}

void setLEDs(int mode) {
  digitalWrite(LED_SINE,     mode == 0);
  digitalWrite(LED_TRIANGLE, mode == 1);
  digitalWrite(LED_SQUARE,   mode == 2);
}

void blinkAll(int times) {
  for (int i = 0; i < times; i++) {
    digitalWrite(LED_SINE, HIGH);
    digitalWrite(LED_TRIANGLE, HIGH);
    digitalWrite(LED_SQUARE, HIGH);
    delay(80);

    digitalWrite(LED_SINE, LOW);
    digitalWrite(LED_TRIANGLE, LOW);
    digitalWrite(LED_SQUARE, LOW);
    delay(80);
  }
}

void setup() {
  pinMode(IN_A, INPUT);
  pinMode(IN_B, INPUT);

  pinMode(LED_SINE, OUTPUT);
  pinMode(LED_TRIANGLE, OUTPUT);
  pinMode(LED_SQUARE, OUTPUT);

  delay(100); // stabilité au démarrage
}

void loop() {
  int mode = getMode();

  if (mode != lastMode) {
    blinkAll(2);   // animation
    setLEDs(mode); // affichage final
    lastMode = mode;
  }
}
